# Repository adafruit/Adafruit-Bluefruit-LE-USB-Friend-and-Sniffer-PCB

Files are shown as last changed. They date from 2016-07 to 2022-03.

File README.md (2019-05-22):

## Adafruit Bluefruit LE USB Friend and Sniffer
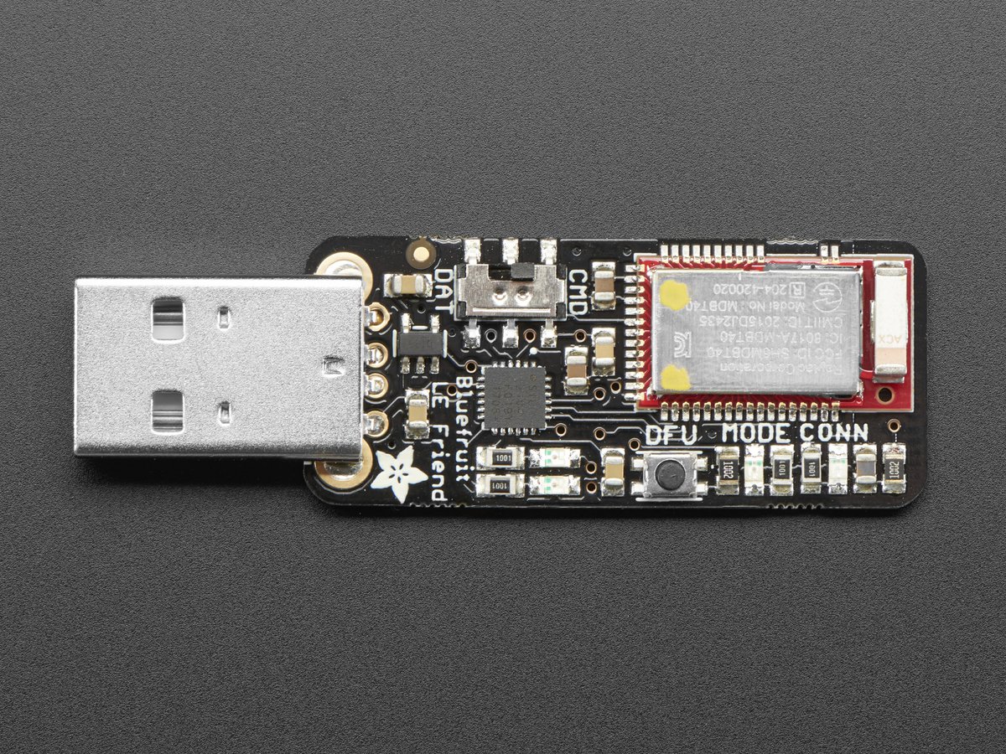
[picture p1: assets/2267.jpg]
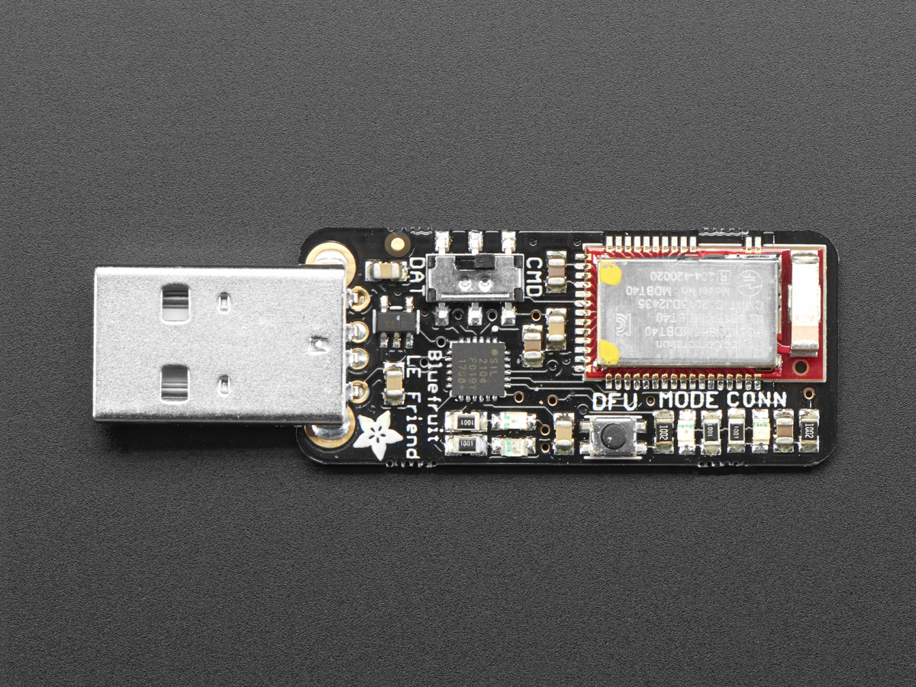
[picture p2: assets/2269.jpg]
&nbsp; <br />
Click to purchase from the Adafruit Shop:
- [Bluefruit LE Friend - Bluetooth Low Energy (BLE 4.0) - nRF51822 - v3.0](https://www.adafruit.com/product/2267)
- [Bluefruit LE Sniffer - Bluetooth Low Energy (BLE 4.0) - nRF51822 - Firmware Version 2](https://www.adafruit.com/product/2269)

The Bluefruit LE Friend is your new BLE BFF! This USB-to-BLE board makes it easy to get your computer talking to your BLE enabled phone or tablet using a standard serial/UART connection.

In it's simplest form, it works on the same principle as a common USB/Serial adapter (the FTDI Friend, for example!). Any data that you enter via your favorite terminal emulator on your development machine will be transferred over the air to the connected phone or tablet, and vice versa, as a basic 'UART' connection.

PCB files for the Bluefruit LE USB Friend and Sniffer
- https://www.adafruit.com/product/2267
- https://www.adafruit.com/product/2269

### License

Adafruit invests time and resources providing this open source design, please support Adafruit and open-source hardware by [purchasing products from Adafruit](https://www.adafruit.com)!

All text above must be included in any redistribution

Designed by Limor Fried/Ladyada for Adafruit Industries.
Creative Commons Attribution/Share-Alike, all text above must be included in any redistribution. 
See license.txt for additional information.

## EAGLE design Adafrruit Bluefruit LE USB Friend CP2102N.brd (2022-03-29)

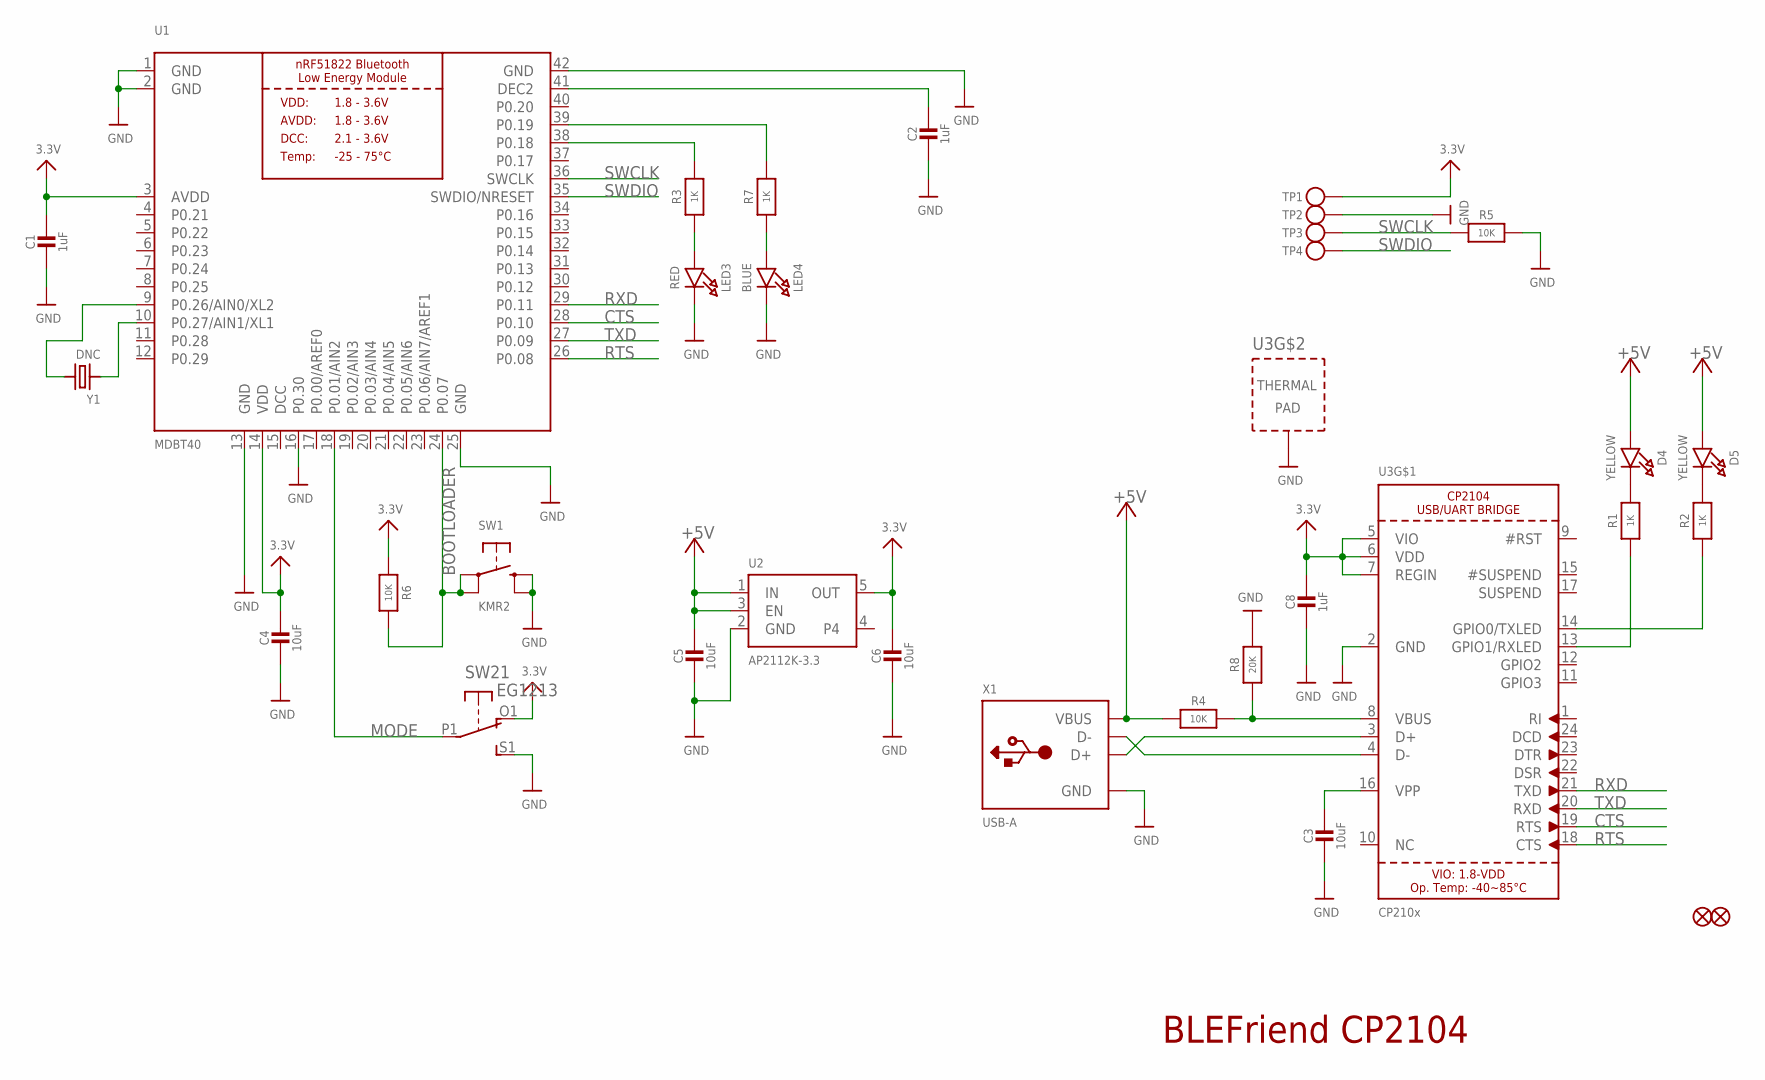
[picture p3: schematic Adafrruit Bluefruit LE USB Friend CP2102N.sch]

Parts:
C1, C2, C8: 1uF; 0603-NO
C3, C4, C5, C6: 10uF; 0805-NO
D4, D5: YELLOW; CHIPLED_0805_NOOUTLINE
FID1, FID2: FIDUCIAL_1MM
LED3: RED; CHIPLED_0805_NOOUTLINE
LED4: BLUE; CHIPLED_0805_NOOUTLINE
R1, R2, R3, R7: 1K; 0603-NO
R4, R5, R6: 10K; 0603-NO
R8: 20K; 0603-NO
SW1: KMR2; BTN_KMR2_4.6X2.8
SW2: EG1213; EG1390
TP1, TP2, TP3, TP4: TESTPOINTROUND2MM; TESTPOINT_ROUND_2MM
U1: MDBT40; BLE_MODULE_RAYTAC_MDBT40
U2: AP2112K-3.3; SOT23-5
U3: CP210x; QFN24_4MM_SMSC
X1: USB-A; USB_A-THM
Y1: DNC; CRYSTAL_CYL_2X6MM_SMT

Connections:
3.3V: C1.1, C4.1, C6.1, C8.1, R6.1, SW2.O1 (O), TP1.P$1, U1.3 (AVDD), U1.14 (VDD), U2.5 (OUT), U3.5 (VIO), U3.6 (VDD), U3.7 (REGIN)
+5V: C5.1, D4.A, D5.A, R4.1, U2.1 (IN), U2.3 (EN), X1.VBUS
BOOTLOADER: R6.2, SW1.A, SW1.A' (P1), U1.24 (P0.07)
CTS: U1.28 (P0.10), U3.19 (RTS)
DCC: U1.15 (DCC)
DEC2: C2.1, U1.41 (DEC2)
GND: C1.2, C2.2, C3.2, C4.2, C5.2, C6.2, C8.2, LED3.C, LED4.C, R5.2, R8.2, SW1.B (S), SW1.B' (S1), SW2.S1 (S), TP2.P$1, U1.1 (GND), U1.2 (GND), U1.13 (GND), U1.16 (P0.30), U1.25 (GND), U1.42 (GND), U2.2 (GND), U3.2 (GND), U3.THERM (TP), X1.GND
MODE: SW2.P1, U1.18 (P0.01/AIN2)
unnamed: U3.4 (D-), X1.D-
unnamed: D4.C, R1.2
unnamed: LED3.A, R3.1
unnamed: C3.1, U3.16 (VPP)
unnamed: R2.1, U3.14 (GPIO0/TXLED)
unnamed: D5.C, R2.2
unnamed: R4.2, R8.1, U3.8 (VBUS)
unnamed: U3.3 (D+), X1.D+
unnamed: R3.2, U1.38 (P0.18)
unnamed: R7.2, U1.39 (P0.19)
unnamed: LED4.A, R7.1
unnamed: U1.9 (P0.26/AIN0/XL2), Y1.2
unnamed: U1.10 (P0.27/AIN1/XL1), Y1.1
unnamed: R1.1, U3.13 (GPIO1/RXLED)
RTS: U1.26 (P0.08), U3.18 (CTS)
RXD: U1.29 (P0.11), U3.21 (TXD)
SWCLK: R5.1, TP3.P$1, U1.36 (SWCLK)
SWDIO: TP4.P$1, U1.35 (SWDIO/NRESET)
TXD: U1.27 (P0.09), U3.20 (RXD)

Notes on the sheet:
BLEFriend CP2104

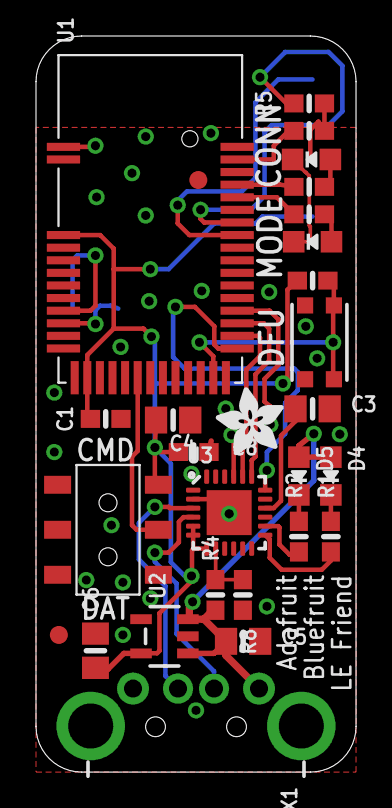
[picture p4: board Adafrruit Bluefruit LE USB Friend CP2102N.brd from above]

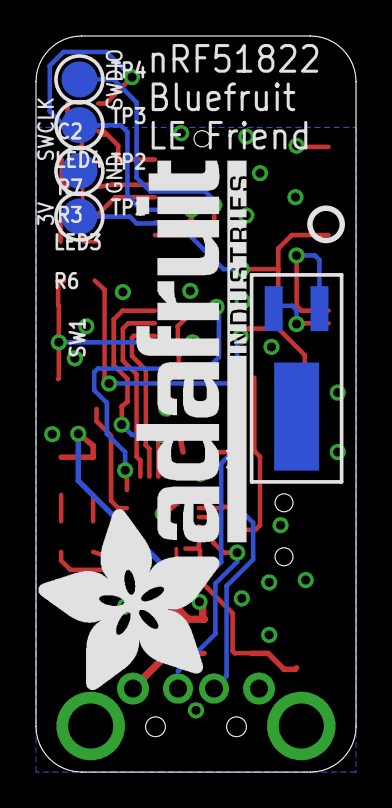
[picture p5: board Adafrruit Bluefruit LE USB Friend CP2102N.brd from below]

Board: 2 copper layers, 17.8 x 40.9 mm, 35 parts (7 on the bottom side), 26 nets.

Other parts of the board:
U$16: PCBFEAT-REV-040
U$22: ADAFRUIT_TEXT_30MM
U$31: ADAFRUIT_3.5MM

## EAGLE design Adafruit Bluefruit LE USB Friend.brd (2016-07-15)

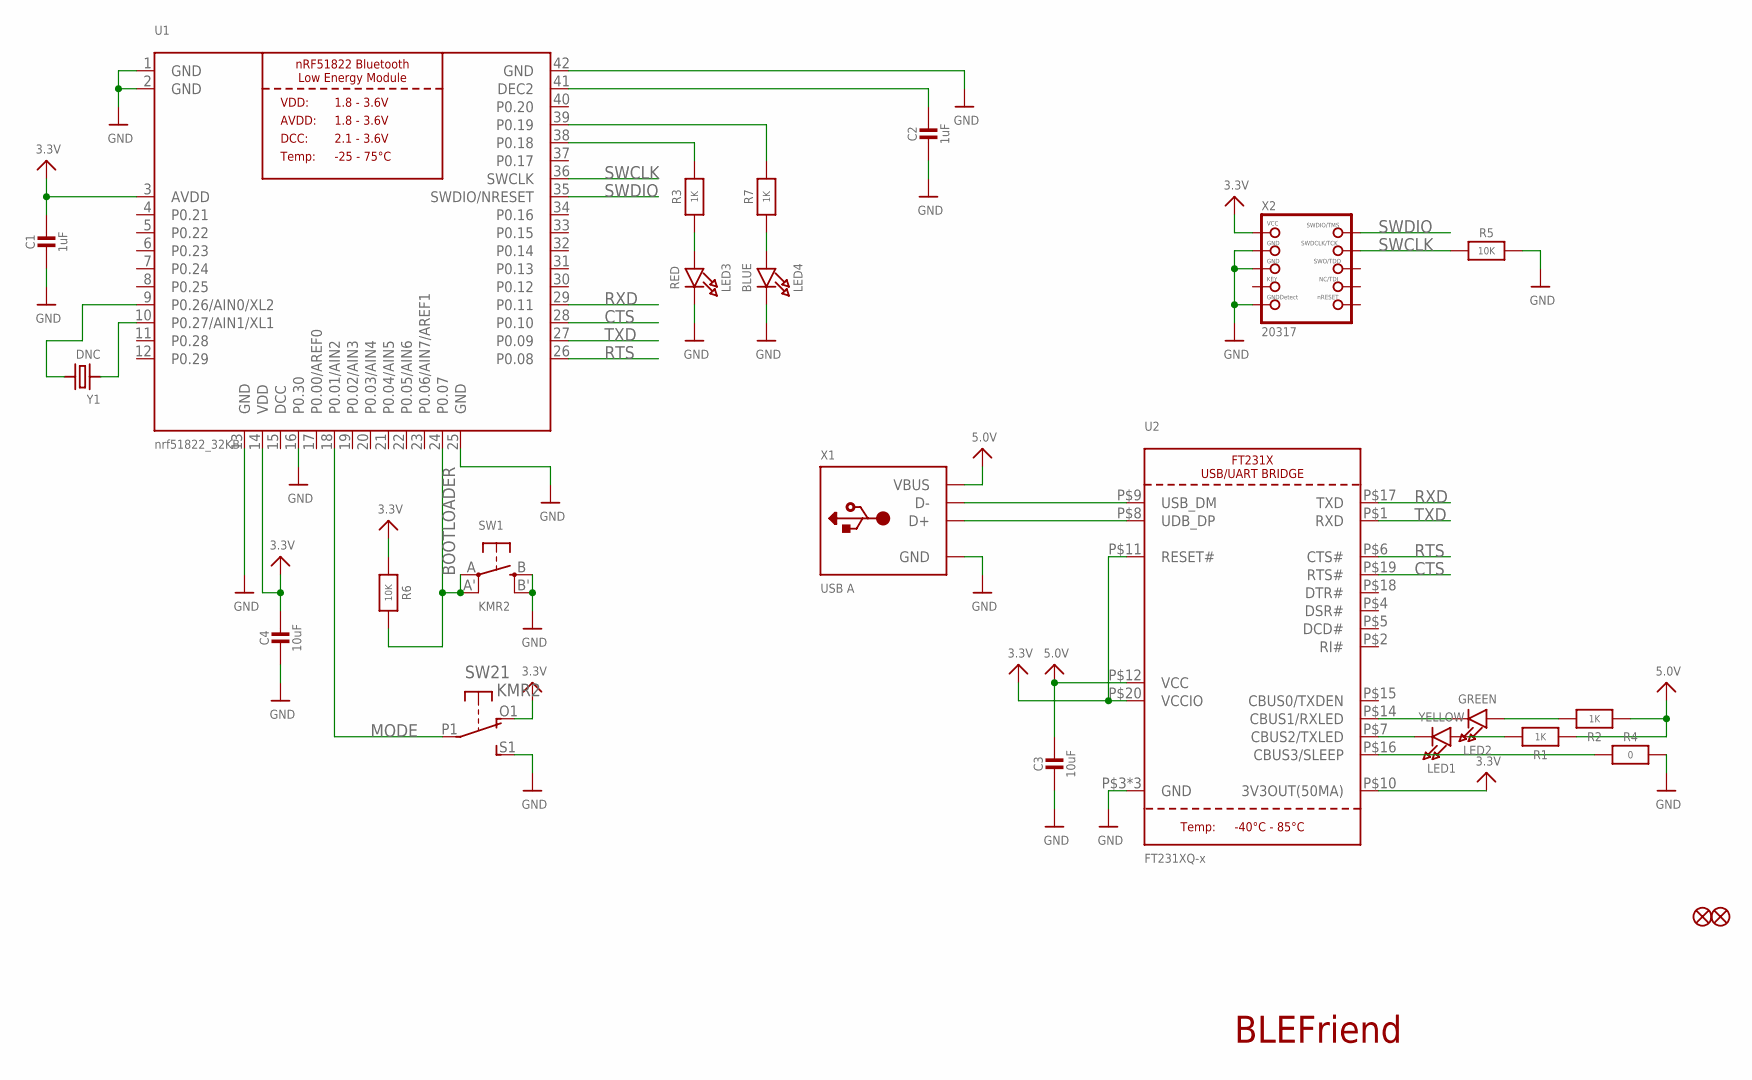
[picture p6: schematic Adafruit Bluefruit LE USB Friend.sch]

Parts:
C1, C2: 1uF; _0805MP
C3, C4: 10uF; _0805MP
FID1, FID2: FIDUCIAL""; FIDUCIAL_1MM
LED1: YELLOW; CHIPLED_0805_NOOUTLINE
LED2: GREEN; CHIPLED_0805_NOOUTLINE
LED3: RED; CHIPLED_0805_NOOUTLINE
LED4: BLUE; CHIPLED_0805_NOOUTLINE
R1, R2, R3, R7: 1K; _0805MP
R4: 0; _0805MP
R5, R6: 10K; _0805MP
SW1: KMR2; BTN_KMR2_4.6X2.8
SW2: KMR2; EG1390
U1: nrf51822_32KB; BLE_MODULE_RAYTAC_MDBT40
U2: FT231XQ-x; QFN20_4MM
X1: USB A; USB_A-THM
X2: 20317; 2X05_1.27MM_BOX_POSTS
Y1: DNC; CRYSTAL_CYL_2X6MM_SMT

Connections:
3.3V: C1.1, C4.1, R6.1, SW2.O1 (O), U1.3 (AVDD), U1.14 (VDD), U2.P$10 (3V3OUT(50MA)), U2.P$11 (RESET#), U2.P$20 (VCCIO), X2.1 (VCC)
5.0V: C3.1, R1.1, R2.1, U2.P$12 (VCC), X1.VBUS
BOOTLOADER: R6.2, SW1.A, SW1.A' (P1), U1.24 (P0.07)
CTS: U1.28 (P0.10), U2.P$19 (RTS#)
DCC: U1.15 (DCC)
GND: C1.2, C2.2, C3.2, C4.2, LED3.C, LED4.C, R4.2, R5.2, SW1.B (S), SW1.B' (S1), SW2.S1 (S), U1.1 (GND), U1.2 (GND), U1.13 (GND), U1.16 (P0.30), U1.25 (GND), U1.42 (GND), U2.P$3 (GND), U2.P$13 (GND), U2.P$21 (GND), X1.GND, X2.3 (GND), X2.5 (GND), X2.9 (GNDDETECT)
MODE: SW2.P1, U1.18 (P0.01/AIN2)
unnamed: LED2.A, R2.2
unnamed: C2.1, U1.41 (DEC2)
unnamed: LED3.A, R3.1
unnamed: LED1.A, R1.2
unnamed: LED1.C, U2.P$7 (CBUS2/TXLED)
unnamed: LED2.C, U2.P$14 (CBUS1/RXLED)
unnamed: R4.1, U2.P$16 (CBUS3/SLEEP)
unnamed: U2.P$8 (UDB_DP), X1.D+
unnamed: U2.P$9 (USB_DM), X1.D-
unnamed: R3.2, U1.38 (P0.18)
unnamed: R7.2, U1.39 (P0.19)
unnamed: LED4.A, R7.1
unnamed: U1.9 (P0.26/AIN0/XL2), Y1.2
unnamed: U1.10 (P0.27/AIN1/XL1), Y1.1
RTS: U1.26 (P0.08), U2.P$6 (CTS#)
RXD: U1.29 (P0.11), U2.P$17 (TXD)
SWCLK: R5.1, U1.36 (SWCLK), X2.4 (SWDCLK)
SWDIO: U1.35 (SWDIO/NRESET), X2.2 (SWDIO)
TXD: U1.27 (P0.09), U2.P$1 (RXD)

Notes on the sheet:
BLEFriend

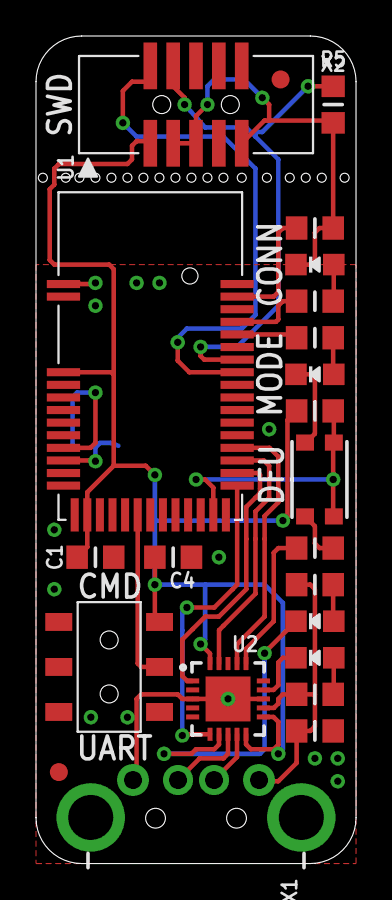
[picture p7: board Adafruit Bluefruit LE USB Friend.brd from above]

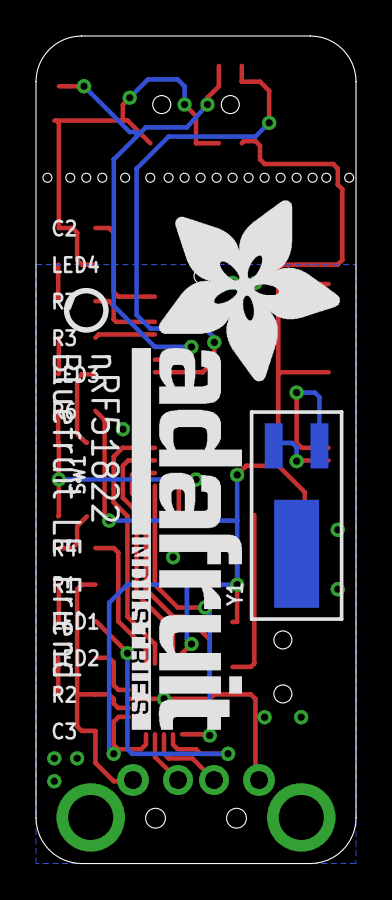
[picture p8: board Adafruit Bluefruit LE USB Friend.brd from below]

Board: 2 copper layers, 17.8 x 46.0 mm, 26 parts (3 on the bottom side), 25 nets.

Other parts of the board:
U$22: ADAFRUIT_TEXT_30MM
U$27: PCBFEAT-REV-056

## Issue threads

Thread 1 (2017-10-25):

Broken file

ankitmcgill, 2017-10-25:
The schematic sch file cannot be opened with Eagle 7.7. Get error

```
Loading Z:/ubuntu_work/Adafruit Bluefruit LE USB Friend.sch ...

Error:

line 8, column 16: This is not an EAGLE file.

```

ankitmcgill, 2017-10-25:
The file was corrupted. Working now. closing issue

Closed 2017-10-25.

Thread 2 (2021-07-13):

V3 PCB?

Friendly0Fire, 2021-07-13:
I tried looking around, but I couldn't find a board layout for the V3 board (without the SWD connector). I'm looking to make a dimensionally accurate 3D printed case for it and it'd be a lot easier to do this with an up to date PCB layout I could use for CAD.

kattni, 2021-07-14:
@Friendly0Fire I have added the latest board files.

Closed 2021-07-14.

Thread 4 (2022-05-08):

How can I get a better scan

ChillVibesMushroom, 2022-05-08:
I've managed to get the sniffer capturing all devices but I noticed sometimes it will capture malformed packets and I was wondering how I can get a better scan from the sniffer. All the steps provided I have followed on installation or is that normal to get malformed packets currently I am at work and I'll have to get back to you in 10 hours have a great day okay.

ChillVibesMushroom, 2022-05-10:
This is what we are looking at here. The BLE Friend is picking up malformed packets.

ladyada, 2022-05-17:
we just run the firmware from nordic, we dont have any other insight into how the firmware works, you could try asking nordic for advice on sniffing BLE they have a helpful forum

Closed 2022-05-17.

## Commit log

2021-07-14 Rename Adafruit Bluefruit LE USB Friend.brd to Adafruit Bluefruit LE USB Friend Original.brd
    [Adafruit Bluefruit LE USB Friend Original.brd]
2021-07-14 Rename Adafruit Bluefruit LE USB Friend Original.brd to Adafruit Bluefruit LE USB Friend.brd
    [Adafruit Bluefruit LE USB Friend.brd]
2021-07-14 Add latest board files.
    [Adafruit Bluefruit LE USB Friend Rev I.brd, Adafruit Bluefruit LE USB Friend Rev I.sch]

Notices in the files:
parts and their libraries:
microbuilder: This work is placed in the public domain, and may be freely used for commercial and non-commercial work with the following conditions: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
